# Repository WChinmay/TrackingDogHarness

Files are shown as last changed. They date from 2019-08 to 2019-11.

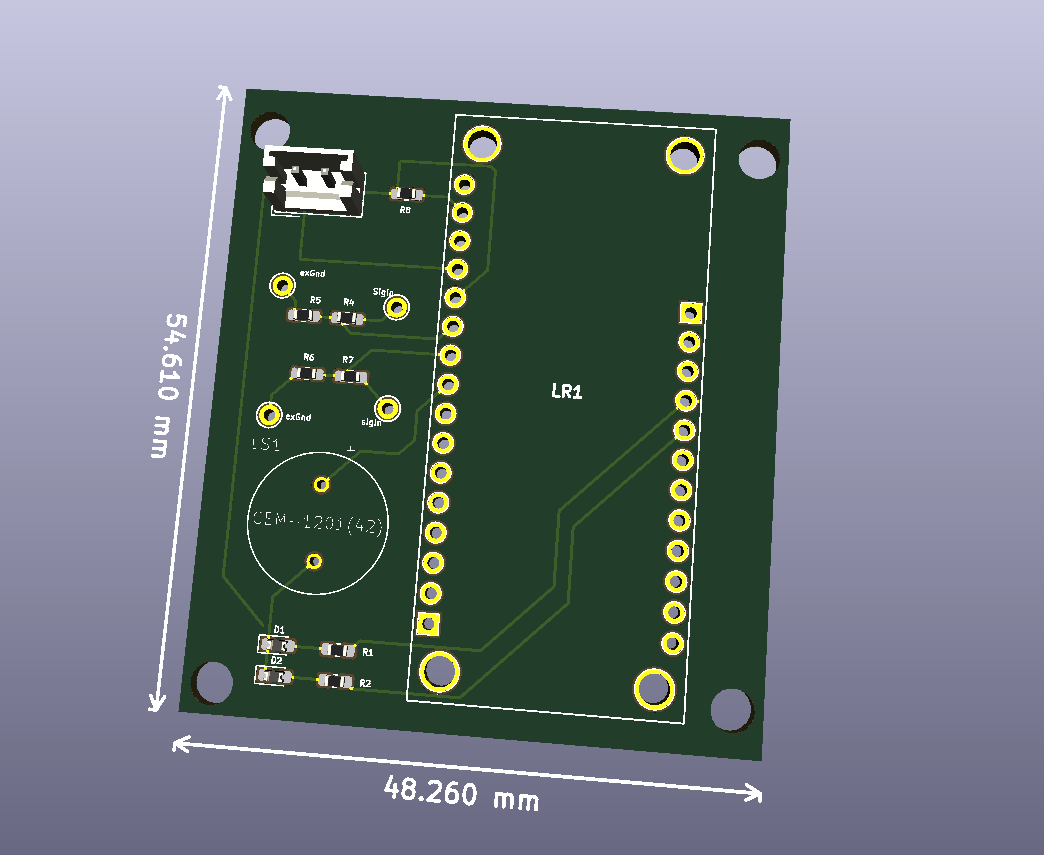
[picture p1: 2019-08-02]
PCBFiles/Block 2 Check off/3dmodel pcb.PNG

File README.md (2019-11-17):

# A Tracking Two-Way Communication Dog Harness that uses LoRa

## Description
This group project was developed for ECE 342 - Junior Design, a class at Oregon State University.

The harness can be used to reliably track your dog up to 0.7 miles (as of this version). It also provides temperature and battery voltage readings. Two other analog sensors can be incorporated into the harness. The battery life has been tested to be more than 12 hours and can probably last more than 48 hours on a single charge.

## Unique Feature
You can use the switch on the Alpha Transceiver to trigger a buzzer on the Beta Transceiver. Hence, your dog will be able to hear the buzzer. You can train your dog to "return" when it hears the buzzer. The buzzer can also be modified to ring at a frequency that only dogs and not humans can hear.

## Project Video
[Here](https://www.youtube.com/watch?v=w3UX0Dp_v24) is a link to the project video.

For more information, please contact:
wchinmay@gmail.com

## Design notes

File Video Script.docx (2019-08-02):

Video Script: 8-11 minutes

1. Introduction (~1 minute) - In this section of the video Chinmay Wadgaonkar, Noah Hoffman, and WeiHao Kuang will introduce themselves in that order. Along with the introduction we will also each state which blocks of the system that we are responsible for. Thus making a nice transition to the contributions part of the video.

Hey! We are team Tele(8) My name is Chinmay Wadgaonkar.

My name is Noah Hoffman.

My name is WeiHao Kuang, Our project is a telemetry device that will be mounted on a doggy harness. The system consists of a ruggedly enclosed transceiver on the harness we call the “Beta transceiver”. This can send GPS, temperature, and battery information to an “Alpha transceiver” that is connected to a MatLab map display at least 0.5 miles away. Also, on the Alpha side, the user can trigger a buzzer on the harness to signal the dog to return.

The 6 blocks that comprise this project are a MATLAB display and Alpha transceiver done by Chinmay, the Beta transceiver and sensing block by Noah, and the enclosure and buzzer sections by WeiHao.

2. Contributions
  a. Individual team members will talk about the parts that they were responsible for along with any specific design choices that they made and the materials they used to make their part. For this part the team members block overviews will be ordered by their first name.
    i. Chinmay Wadgaonkar (~1-2 minutes) - Chinmay will talk about the blocks that he was responsible for: the Alpha Transceiver and the MATLAB GUI display.

I was in charge of the Matlab display and the Alpha transceiver. The Alpha transceiver is the part of the system that receives temperature, battery voltage and temperature data from the beta and then passes it on to the the Matlab script through serial communication. The Alpha transceiver is also the part of the system which lets the user trigger a “buzzer” on the beta side by flipping a switch. I was also responsible for the two way communication incorporated in our system as one of our engineering requirements. I wrote the software which would help the alpha side detect if the switch is flipped and then would generate a “tone” of 4699 Hz. This can be modified to

    ii. Noah Hoffman(~1-2 minutes) - Noah will elaborate on the parts that he was responsible for: the Beta Transceiver and the Sensor Block.

With the Beta transceiver and the sensor block located on the harness, my job was a mix of hardware and software. The brains of our system are two Adafruit 32u4 LoRa feathers on either end communicating wirelessly. I wrote the software to reliably interpret and send battery, temperature, and and GPS data from the Beta feather to the Alpha feather. For the temperature we used a 10k Ohm Thermistor and our GPS was an add-on board built specifically for the feather microcontroller we were using.

    iii. WeiHao Kuang(~1-2 minutes) - WeiHao will explain his blocks which were the system enclosure and the system PCB.

I was in charge of the buzzer block and the system enclosure. The buzzer is integrated on the system PCB, which was designed using KiCad. Essentially the buzzer is used to call for the dog to come back to the owner when it is activated. To activate it we can simply flip a switch on the beta transceiver and through two ways serial communication was can create an audible beep to get the dog to return. The system enclosure designed with ruggedness in mind so that the system can endure various tests that are designed to test its limits, such as the drop system drop test and temperature extreme test.

  b. Evidence of collaboration (~1-2 minutes) - For this section of the video we will talk about the approach the team had for the finishing the project. Noah and Chinmay will talk about communicating over LoRa, and Weihao will talk about how the PCB and enclosure interact with the rest of the blocks. Also in this section of the video each member will talk about a challenge that they came across during the project and they will explain how they went about solving these with the help of other team members. (Collaboration video may be included).
3. Demo (> 2 minutes) - For the demo section of the video we will show a video including all the components of our whole system. We will elaborate in-depth about the functions of our blocks and Chinmay will introduce the entire system. Noah will talk about the intended application of the system. After that, Weihao will narrate as the other members show the system functioning.
4. Take-away Message/Improvement (~1 minute) - In this section of the video, Chinmay will talk about any future improvements that we can make to the system. Also, time willing, we may add possible applications of the system, Noah talking about including multiple beta receivers, and Weihao talking about path tracking and learning. In this section we will also each reflect on the project and what we took away from working on the project as a team.

Chinmay Wadgaonkar Noah Hoffman WeiHao Kuang

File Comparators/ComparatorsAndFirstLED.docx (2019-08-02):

Comparator.raw 5.OV

V(signal)

Vin006)

4.5V

4.0V

3.5V

3.ovh

2.5V

2.0v

1.5V

1.0v

0.5V

0.00+

Oms

2ms

4ms

6ms

8ms

10ms

12ms

14ms

16ms

18ms

Comparator.asc

-Vec

R1

R3

R4

R9

1000

1000

1000

1000

1000

Signal

R5

+

LT1017

2.2k

R6

+4211017

2.95

R7

1111017

2.2k

__ENU

411017

2.2k

v2 vi ŞINE(2.5 2.5 1k)

tran

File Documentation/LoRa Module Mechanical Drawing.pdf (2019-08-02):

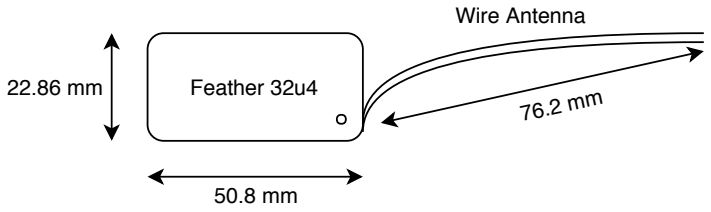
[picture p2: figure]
Feather 32u4; Wire Antenna

## Side View

## Top View

## Feather Module Mechanical Drawings

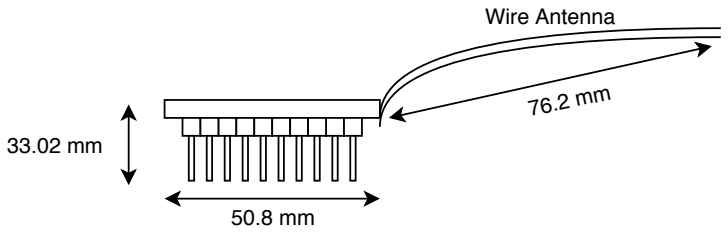
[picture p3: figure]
Wire Antenna

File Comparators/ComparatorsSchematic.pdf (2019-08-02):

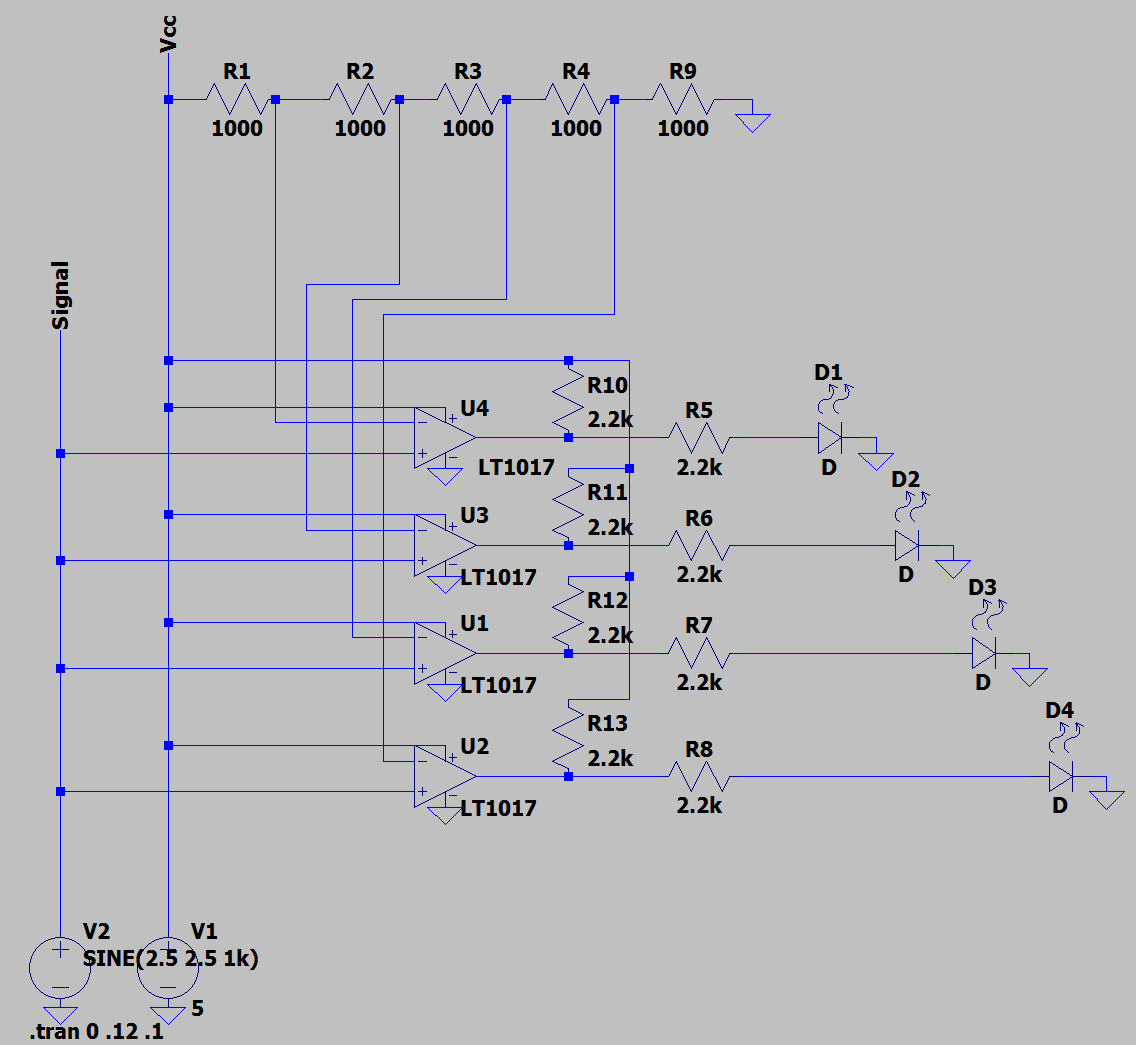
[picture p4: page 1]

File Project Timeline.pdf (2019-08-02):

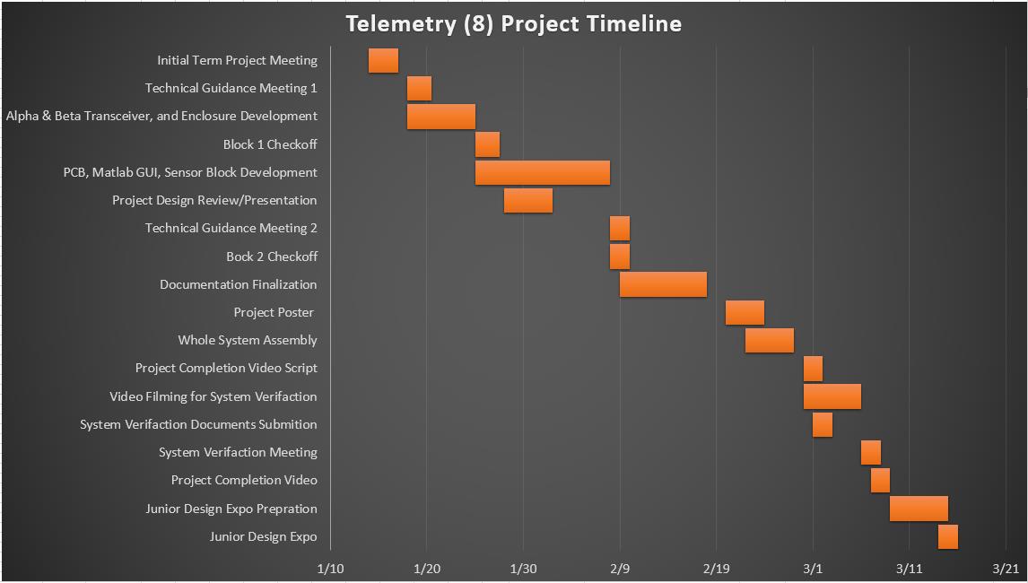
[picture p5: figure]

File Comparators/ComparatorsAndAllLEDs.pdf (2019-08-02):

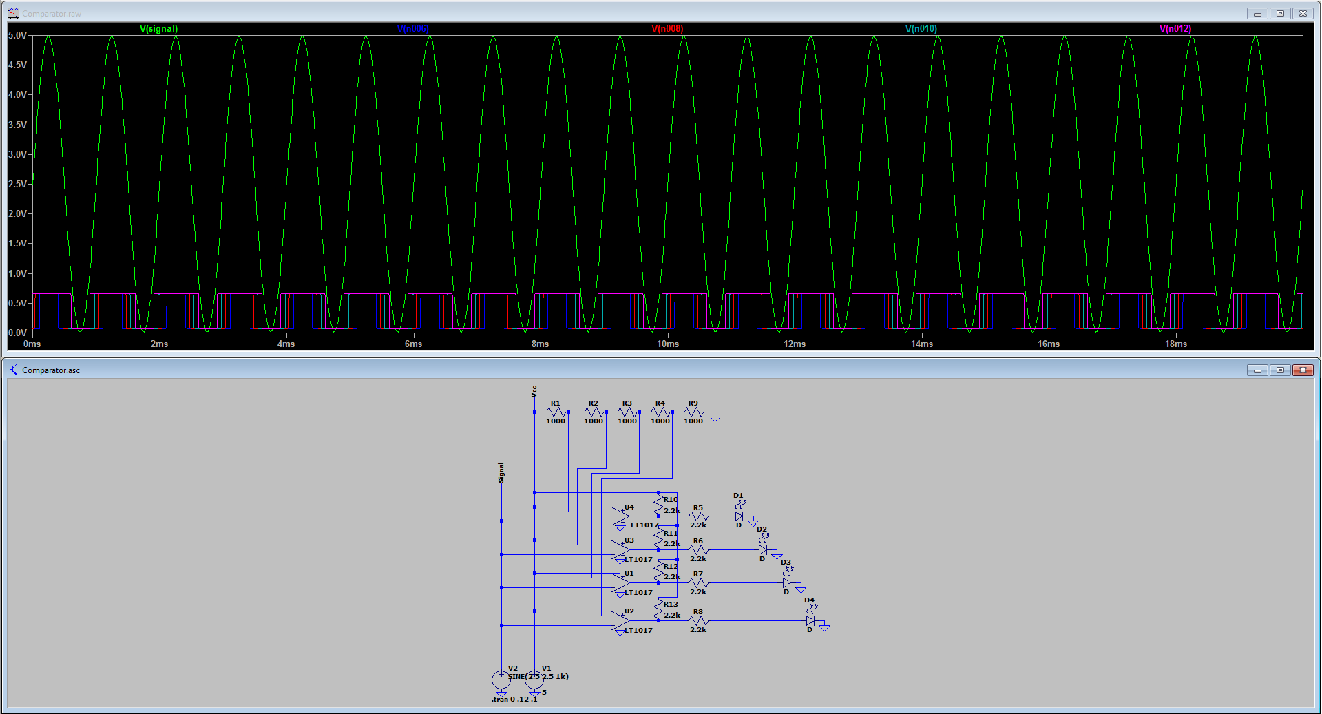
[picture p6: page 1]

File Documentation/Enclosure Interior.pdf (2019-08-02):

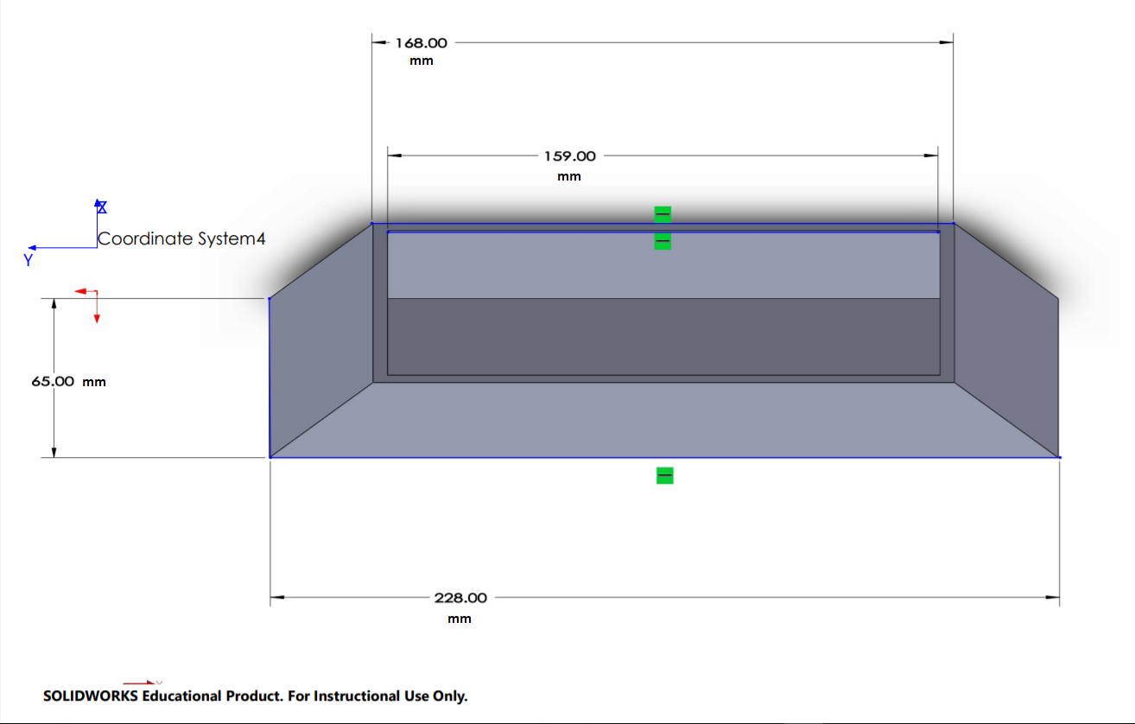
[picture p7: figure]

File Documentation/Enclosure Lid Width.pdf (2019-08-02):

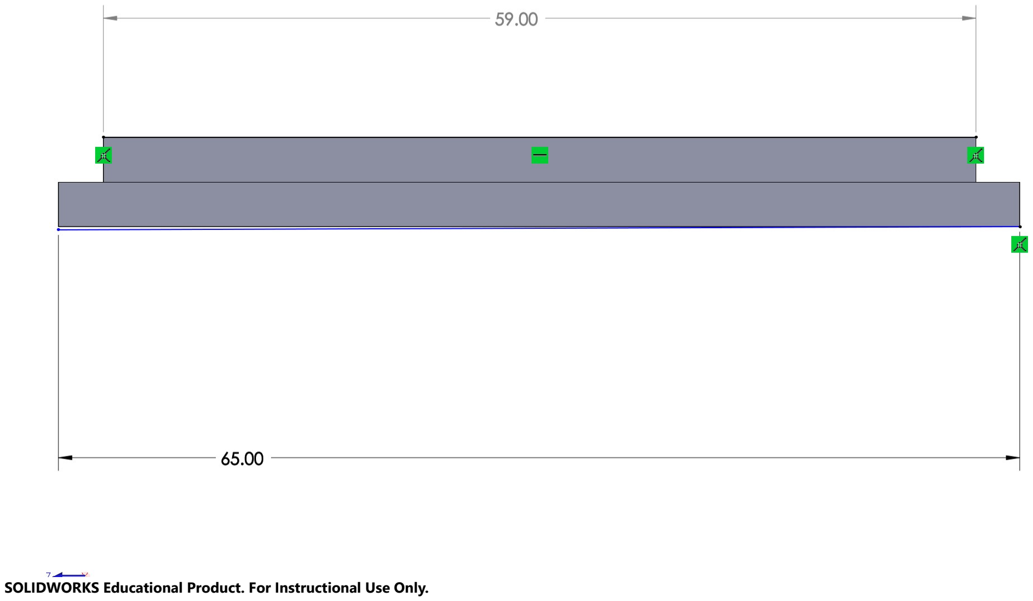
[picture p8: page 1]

SOLIDWORKS Educational Product. For Instructional Use Only.

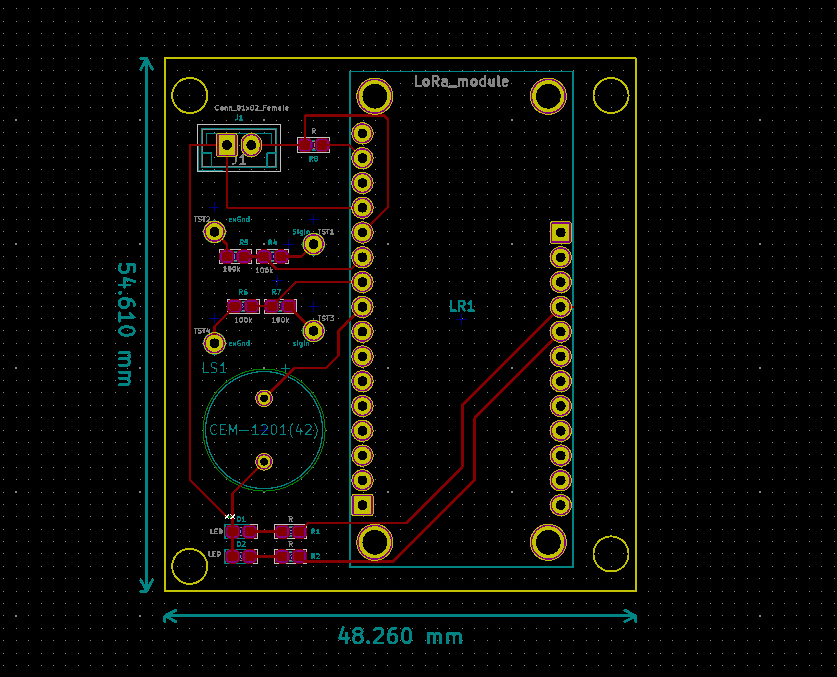
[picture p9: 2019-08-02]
PCBFiles/Block 2 Check off/pcbMain.PNG

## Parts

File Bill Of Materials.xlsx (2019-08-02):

Brand | Model/ Value/Type | Description | Foot Print | Reference | Qty | Cost | Link | DigiKey
Adafruit | Feather 32u4 RFM95 LoRa Radio | Microcontroller and Radio |  | LR1 (Alpha) | 2 | $69.90 | https://www.adafruit.com/product/3078 | ----
Adafruit | Stacking Headers | Header Pins | --- | ---- | 2 | $2.50 | https://www.adafruit.com/product/2830 | ----
Adafruit | FeatherWing | GPS Sensor | --- | ---- | 1 | $39.95 | https://www.adafruit.com/product/3133 | ----
 |  |  |  |  |  |  |  | ----
WlshiOT | B07LCKNN4H | U.FL IPEX to SMA Connector Antenna | --- | ---- | 1 | $11.89 | https://www.amazon.com/gp/product/B07LCKNN4H/ref=ppx_od_dt_b_asin_title_o00_s00?ie=UTF8&psc=1 | ----
Good2Go | Good2Go Pack Leader Green | Dog Harness | --- | ---- | 1 | $14.99 | https://www.petco.com/shop/en/petcostore/product/good2go-pink-dog-backpack | ----
ArtMinds | 16oz. Semi-Gloss DIY Outdoor Paint | Paint | ---- | ---- | 1 | $16.00 | https://www.michaels.com/16oz-semigloss-diy-outdoor-paint-by-artminds/M10515505.html | ----
Adafruit | ICR18650 Lithium Ion Battery 3.7 V 4400 mAh | Lithium Ion Batteries | ---- | ---- | 2 | $49.90 | https://www.adafruit.com/product/354 | ----
OSH Park | Custom Design | PCB | --- | ---- | 3 | $20.55 | https://oshpark.com/ | ----
Syncwire | Super-Durable Nylon Braided Fast Sync&Charging Cord | Mircro Usb Cable | --- | ---- | 2 | $7.99 | https://www.amazon.com/Micro-Cable-Android-Charger-Super-Durable/dp/B01GFB1SLC | ----
DigiKey | 1.37K Ohm (ERJ-3EKF1371V) | Resistor | R_0603_HandSoldering | R1, R2 | 2 | $0.20 | https://www.digikey.com/product-detail/en/panasonic-electronic-components/ERJ-3EKF1371V/P1.37KHCT-ND/198084 | P1.37KHCT-ND
DigiKey | 150K Ohm (ERJ-3GEYJ154V) | Resistor | R_0603_HandSoldering | R4, R5, R5, R7, R8 | 5 | $0.50 | https://www.digikey.com/product-detail/en/panasonic-electronic-components/ERJ-3GEYJ154V/P150KGCT-ND/134977 | P150KGCT-ND
DigiKey | CEM-1201 (42) | Buzzer | CEM-1201_42 | CEM-1201(42) | 1 | $0.74 | https://www.digikey.com/product-detail/en/cui-inc/CEM-1201-42/102-1151-ND/412410 | 102-1151-ND
DigiKey | LED (ERJ-3GEYJ154V) | LED | LED_0603_HandSoldering | D1, D2 | 2 | $0.44 | https://www.digikey.com/product-detail/en/rohm-semiconductor/SML-D12V1WT86/SML-D12V1WT86CT-ND/5843857 | SML-D12V1WT86CT-ND
DigiKey | Female JST connector (ERJ-3GEYJ154V) | JST connector | Pin_Header_Straight_1x02_Pitch2.54mm | J1 | 1 | $0.11 | https://www.digikey.com/product-detail/en/harwin-inc/M20-9990246/952-2262-ND/3728226 | 952-2262-ND
OCR | 10K Ohm Thermal Sensor (5pc) | Thermistor | ---- | ---- | 1 | $9.99 | https://www.amazon.com/OCR-Waterproof-Digital-Thermal-Temperature/dp/B0185P4MVO?s=gateway | ----
Permatex | Permatex® Clear RTV Silicone Adhesive Sealant | Sealant | ---- | ---- | 1 | $5.49 | https://www.permatex.com/products/adhesives-sealants/sealants/permatex-clear-rtv-silicone-adhesive-sealant/ | ----
RadioShack | Project Enclosure (4x2x1-Inch) | Small enclosure | ---- | ---- | 1 | $6.00 | https://www.radioshack.com/products/radioshack-project-enclosure-4x2x1 | ----
XSories | Bendy Flexible Camera Tripod For GoPro, Digital, And Action Sports Cameras | Tripod Mount | ---- | ---- | 1 | $30.99 | https://www.amazon.com/dp/B00OKYYVDO/ref=twister_B00W52UZJC?_encoding=UTF8&psc=1 | ----
TekBots | Custom Design | Body of 3D printed enclosure | ---- | ---- | 1 | $38 | http://eecs.oregonstate.edu/education/3dprinter/ | ----
TekBots | Custom Design | Lid of 3D printed enclosure | ---- | ---- | 1 | $15 | http://eecs.oregonstate.edu/education/3dprinter/ | ----
ThingM | USB Extension cable, 5ft | USB extension cable | ---- | ---- | 1 | $3.00 | http://buy.thingm.com/USB-Extension-cable-5-ft_p_37.html | ----
Uxcell | Uxcell a12081700ux0133 Toggle Switch | Switch | Pin_Header_Straight_1x02_Pitch2.54mm | SW1 | 1 | $4.24 | https://www.amazon.com/Uxcell-a12081700ux0133-Toggle-Terminal-Latching/dp/B00RV9ULFM?s=industrial | ----

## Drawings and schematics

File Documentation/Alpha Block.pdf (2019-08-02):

# Drawing 22.86mm

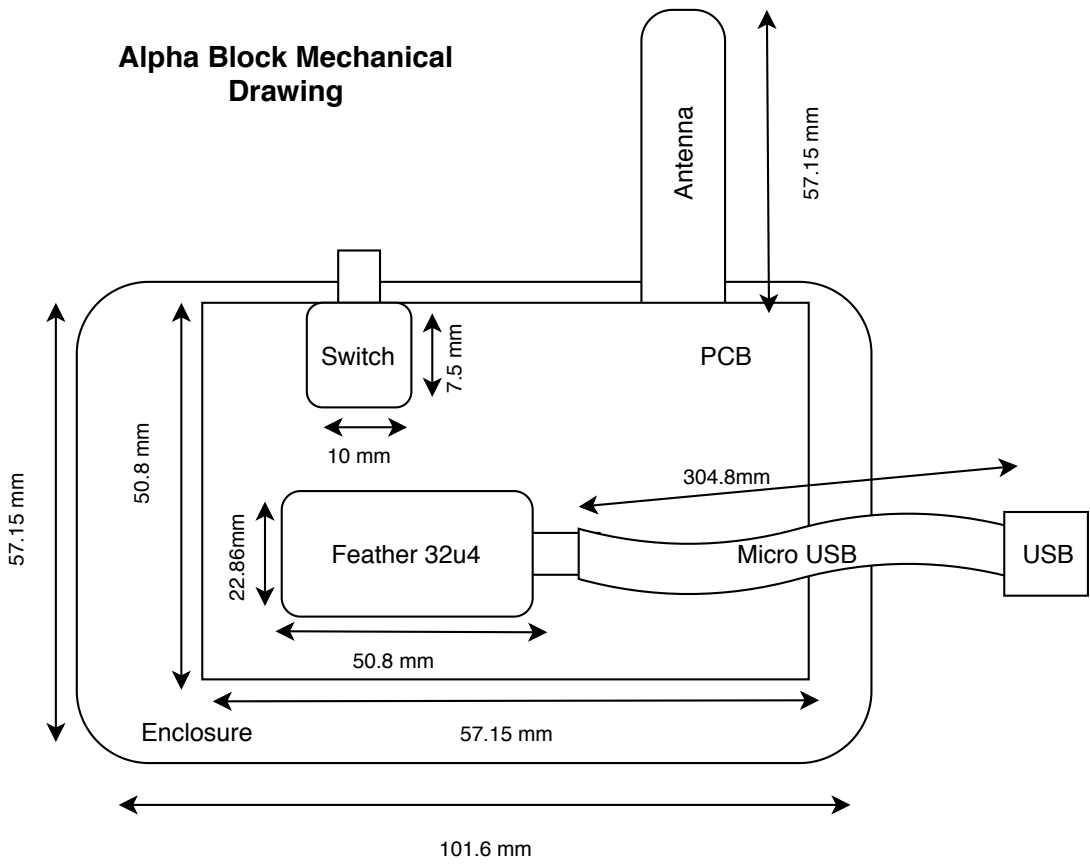
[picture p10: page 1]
Feather 32u4; Micro USB; Switch; USB; PCB; Antenna; Enclosure

Alpha Block Mechanical

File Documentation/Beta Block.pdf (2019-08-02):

# PCBAntenna

# Drawing 22.86mm

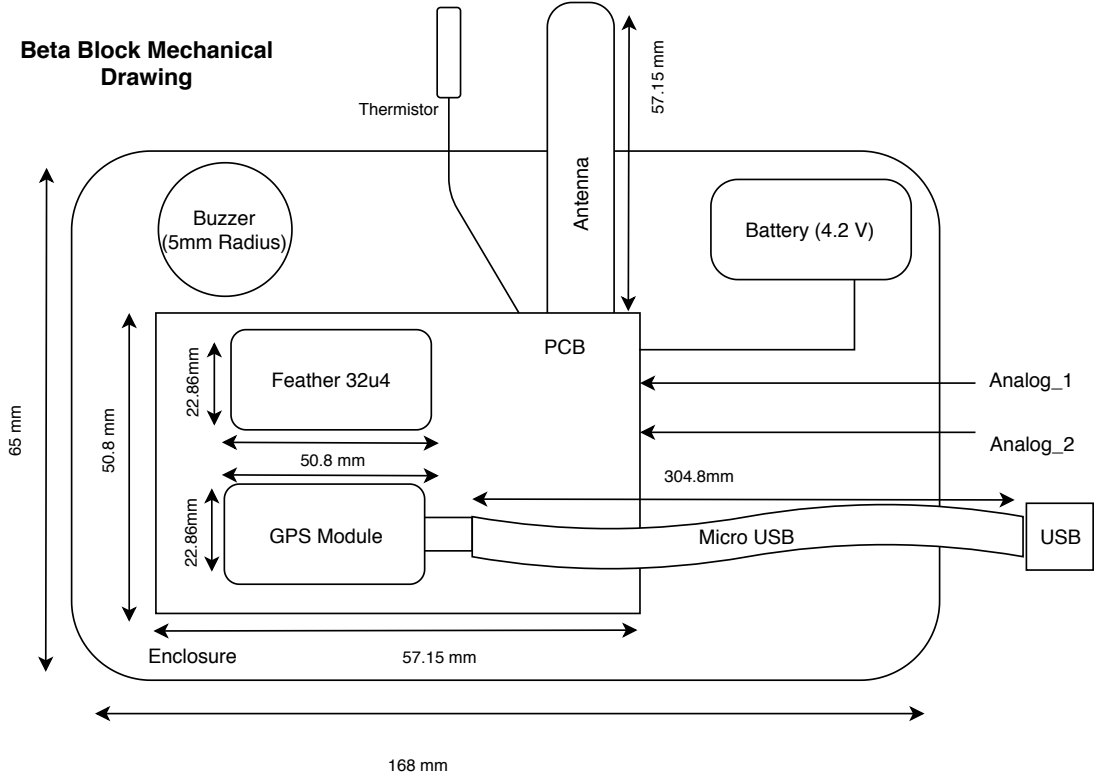
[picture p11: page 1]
Feather 32u4; Micro USB; USB; Enclosure; GPS Module; Buzzer (5mm Radius); Thermistor; Analog_1; Analog_2; Battery (4.2 V)

Beta Block Mechanical

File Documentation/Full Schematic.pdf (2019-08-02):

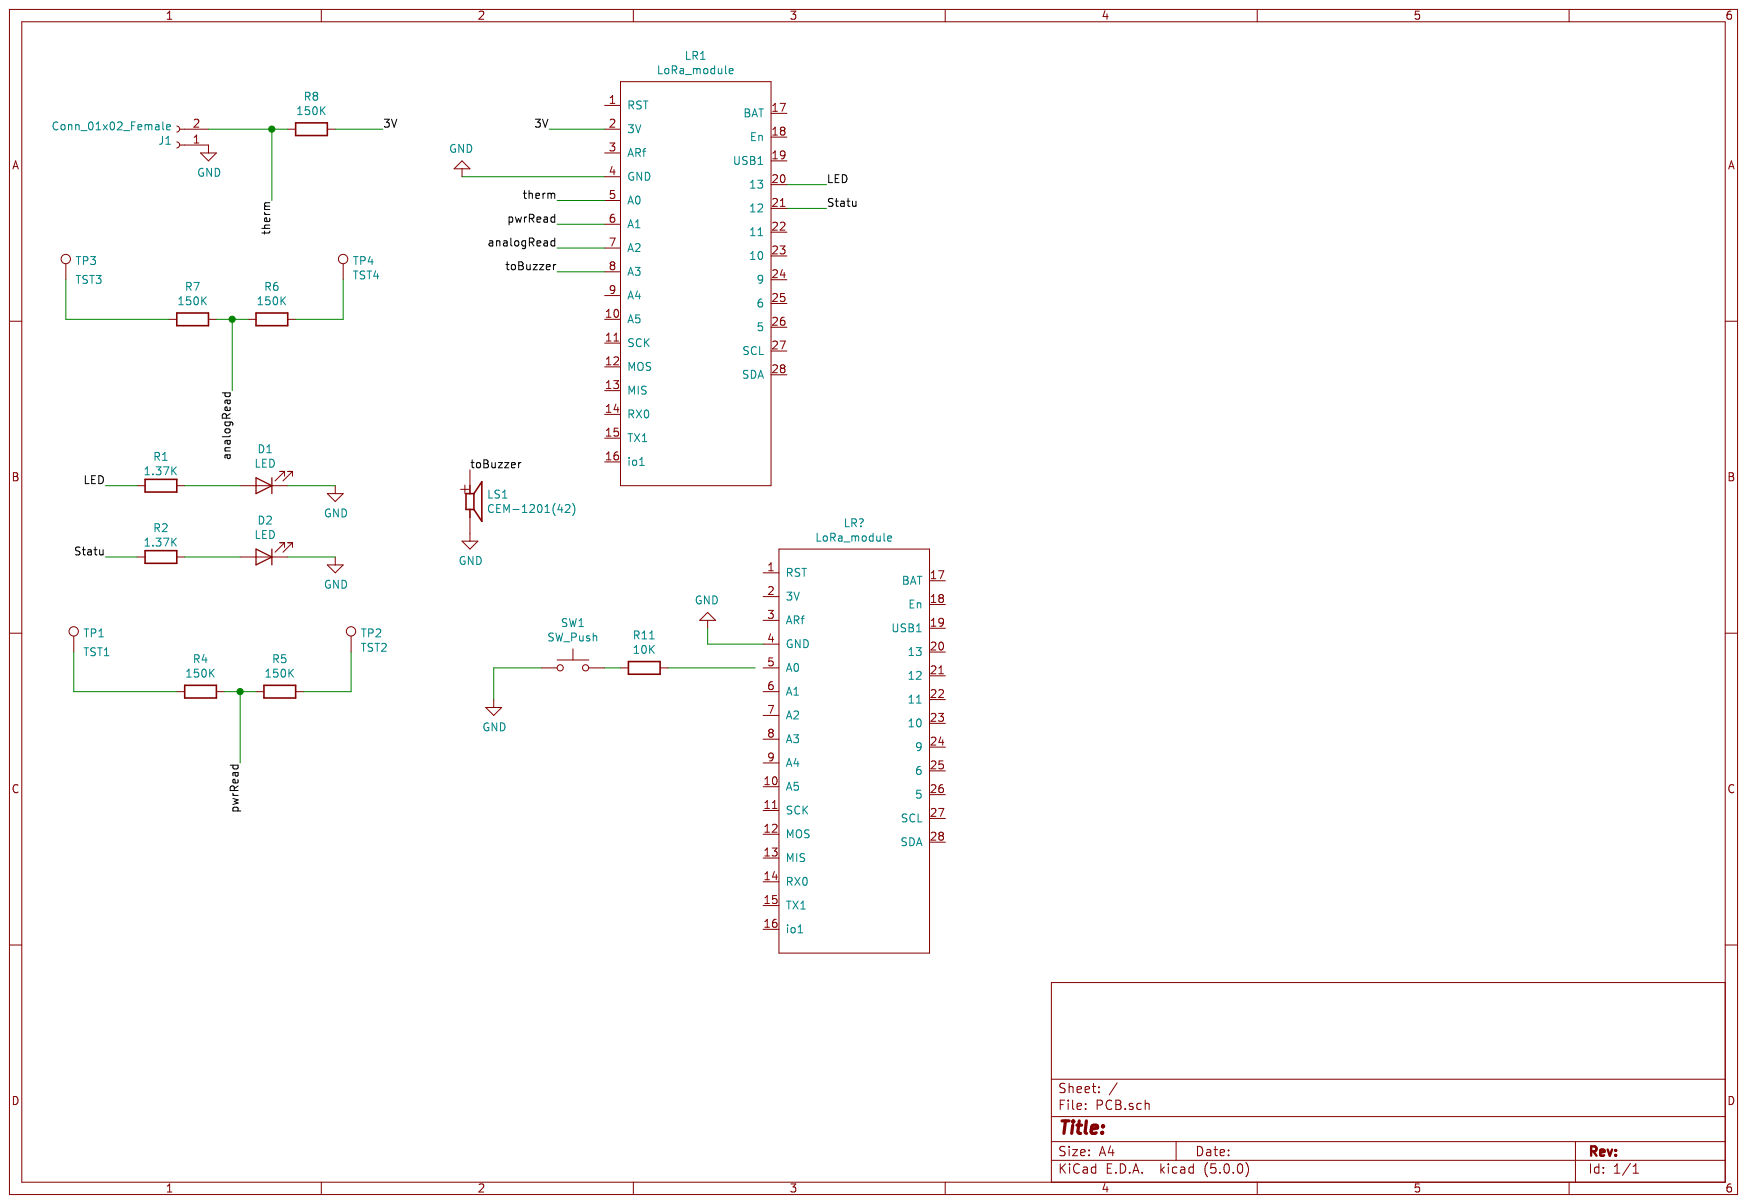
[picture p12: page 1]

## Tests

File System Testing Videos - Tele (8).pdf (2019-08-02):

| Customer Requirement | Engineering Requirement | Video Link
1 | The system must operate a long time. | The system must log and transmit data for at least 12 hours on a single charge. | https://www.youtube.com/watch?v=tkDF9gEU2gM (https://www.youtube.com/watch?v=tkDF9gEU2gM)
2 | The system must be accurate. | The system must log GPS data with at least a 10 meter accuracy and 2 analog voltages from 0.2 -4.5V within 5% or 0.1V of real values, whichever is larger. | https://youtu.be/nMwKtgHTGS 0 (https://youtu.be/nMwKtgHTGS0)
3 | The system needs to be robust. | The system will function to all other requirements while: Being submerged to 1 cm of depth for one second, operating at -10°C, operating above 85°C, and after being dropped on concrete from 3 feet at least 5 times. | https://www.youtube.com/watch?v=rk-2Pc-Hki8&t=4s (https://www.youtube.com/watch?v=rk-2Pc-Hki8&t=4s)
4 | The system must transmit data. | The system must transmit its measurements at least 0.5 miles with at least 95% of the packets being received by the the alpha system over an hour. | https://www.youtube.com/watch?v=7LX2uhGYKJg (https://www.youtube.com/watch?v=7LX2uhGYKJg)
5 | The system must present data. | The system must display data in Matlab, with a professional looking overlay of a satellite map image. | https://www.youtube.com/watch?v=-FKc55mf-XE&t=7s (https://www.youtube.com/watch?v=-FKc55mf-XE&t=7s)
6 | The system must be lightweight. | The beta side of the system must be light enough to be wearable by a dog. Hence, the beta system can weigh up to 7 pounds or 12% of the dog’s body weight, whichever is less. | https://www.youtube.com/watch?v=5BAzrrR3Tn0 (https://www.youtube.com/watch?v=5BAzrrR3Tn0)
7 | The user can remotely trigger a bell sound on the beta-transceiver. | The system has two way communication. A button press by the user on the alpha side must trigger a buzzer on the beta side of the system. | https://www.youtube.com/watch?v=OC4kbGjPUW8 (https://www.youtube.com/watch?v=OC4kbGjPUW8)

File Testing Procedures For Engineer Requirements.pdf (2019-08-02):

1) Customer Requirement: System must operate a long time.
Engineering Requirement: The system must log and transmit data for at least 12 hours on a single charge.
a) To test this requirement for our system we will keep both the alpha and beta transceivers on for 12 hours. The alpha transceiver will keep a log file that will check whether the beta transceiver is still running. If the log file consists of data that is consistent and the data entries correspond to 12 hours of operations, the test will be completed and passed.
2) Customer Requirement: The system must be accurate.
Engineering Requirement: The system must log GPS data with at least a 10 meter accuracy and 2 analog voltages from 0.2 - 4.5V within 5% or 0.1V of real values, whichever is larger.
a) For testing the GPS accuracy we will use 3 known locations and their GPS coordinates. The system will gather gps data at the known location for 5 minutes. If the average of all the GPS data is within 10 metres of the known GPS coordinates, the test passes.
b) For the 2 analog voltage test the system will read in a voltage from 0.2V to 4.5 V by placing an input voltage to the onboard voltage dividers which will be sent to the alpha transceiver and stored onto a log file using MATLAB. If the values that are stored onto MATLAB are within 5% or 0.1V of the real value (whichever is larger), then the test passes.
3) Customer Requirement: The system needs to be robust:
Engineering Requirement:The system will function to all other requirements while: Being submerged to 1 cm of depth for one second, operating at -10°C, operating above 85°C, and after being dropped on concrete from 3 feet at least 5 times
a) Testing the Water Blocking Ability of the Enclosure
i) For this test we would need to fill a sink of water, then line the enclosure with paper towels so that it will be visible if water leaks into the enclosure.
ii) | Next we will fully submerged (1 cm depth) into water for one second then
| take it out. If the paper towels inside are not stained from submerging the
| enclosure in the water then this part of the test is passed.
b) Temperature Operation Range of the Enclosure: Checking if the enclosure can operate in -10℃ or Lower temperature (Cold Extreme).
i) First place the system into a freezer that is -10 degrees. Next, start a
| timer for 5 minutes and check back on the system enclosure when the
| time is up. If the system is still operational and data is being sent to the
| alpha-transceiver for the duration of the five minutes then this test passes.

c) Checking if the enclosure can operate and 85℃ or Higher (Heat Extreme)
i) First preheat the oven to 87 degrees celsius, and place the system in it, Set a timer for 10 minutes and check the enclosure when the time is up. Immediately check for structural weaknesses, if there are not any then the enclosure passed the heat extreme verification test.
d) Drop Shock Robustness
i) For this test we need to drop that enclosure which will be in the dog harness 5 times from a height of 3 feet on concrete.This test will be conducted when the when both beta and the alpha transceivers are running to show that the system will survive and continue to operate. If the system is still transmitting data after the series of 5 drops then this test is passed.
4) Customer Requirement: The system must transmit data.
Engineering Requirements: The system must transmit its measurements at least 0.5 miles with at least 95% of the packets being received by the the alpha-transceiver over an hour.
a) For this test we will be be sending the packet numbers from the beta to alpha transceiver. On both transceivers we will be keeping running totals of the amount of packets during operation which will be over the hour for this test. Once the hour has passed, we will take that ratio of the packets received by the alpha transceiver over the packets sent by that beta transceiver; it that ratio if at least 95 percent that this part of the test is passed.
5) Customer Requirement: The system must present data.
Engineering Requirement: The system must display data in Matlab, with a professional looking overlay of a satellite map image.
a) To test this engineering requirement, we will show that the data retrieved from the beta transceiver can be displayed on the MATLAB GUI with the temperature, battery voltage, the two analog voltage readings, and the GPS data.
`
6) Customer Requirement: The system must be lightweight.
Engineering Requirement: The beta side of the system must be light enough to be wearable by a dog. Hence, the beta system can weigh up to 7 pounds or 12% of the dog’s body weight, whichever is less.
a) To test this requirement we will just weigh the system on a balanced and accurate scale and if the system is less than 7 pounds this test is passed.

7) Customer Requirement: The user can remotely trigger a bell sound on the beta-transceiver.
Engineering Requirement: The system has two way communication. A button press by the user on the alpha side must trigger a buzzer on the beta side of the system.
a) For this test, to show that the system has two way communication, the alpha-transceiver will trigger a response on the beta-transceiver side of the system. A mechanical switch will trigger the beta-side buzzer running at 4699 Hz. If a buzzer sound is triggered when the mechanical switch on the alpha side is pressed then this test passes.

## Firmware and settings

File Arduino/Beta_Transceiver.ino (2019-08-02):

/* Include header files */
#include <Adafruit_GPS.h>
#include <SoftwareSerial.h>
#include <SPI.h>
#include <RH_RF95.h>
#include <stdlib.h>
#include <string.h>

/* RFM95 definitions */
#define RFM95_CS 8
#define RFM95_RST 4
#define RFM95_INT 7

/* Thermistor constants */
#define THERMISTORNOMINAL 10000
#define SERIESRESISTOR 150000   // Change this to the value of the series resistor if the resistor on the current PCB is changed

int16_t packetnum = 0;    // 16 bit integer to hold packets
char latBuffer[10];       // To hold latitude from GPS
char longBuffer[10];      // To hold longitude from GPS
String temp;              // To hold temperature from thermistor

/* Default constants for dummy data */
float Vbatt = 3.20;
float temperature = 70.42;

/* Pin declarations */
#define VBATPIN A9    // Pin for battery voltage
#define TEMPPIN A0    // Pin for temperature
#define PWMPIN  A3    // Pin for pulse width modulation
#define ANALOG1 A1    // Pin for analog reading 1
#define ANALOG2 A2    // Pin for analog reading 2

// Change to 434.0 or other frequency, must match RX's freq!
#define RF95_FREQ 915.0

// Singleton instance of the radio driver
RH_RF95 rf95(RFM95_CS, RFM95_INT);

// The name of the hardware serial port
#define GPSSerial Serial1

// Connect to the GPS on the hardware port
Adafruit_GPS GPS(&GPSSerial);
     
// Set GPSECHO to 'false' to turn off echoing the GPS data to the Serial console
// Set to 'true' if you want to debug and listen to the raw GPS sentences
#define GPSECHO false

/* Start millisecond timer for GPS */
uint32_t timer = millis();


void setup()
{
  //while (!Serial);  // uncomment to have the sketch wait until Serial is ready
  pinMode(RFM95_RST, OUTPUT);   // Set initila pin mode
  digitalWrite(RFM95_RST, HIGH);    // Set initial pin mode
  // connect at 115200 so we can read the GPS fast enough and echo without dropping chars
  // also spit it out
  Serial.begin(115200);   // Start serial at 115200 baud
  // Serial.println("Adafruit GPS library basic test!");
     
  // 9600 NMEA is the default baud rate for Adafruit MTK GPS's- some use 4800
  GPS.begin(9600);
  GPS.sendCommand(PMTK_SET_NMEA_OUTPUT_RMCGGA);
  // Set the update rate
  GPS.sendCommand(PMTK_SET_NMEA_UPDATE_1HZ); // 1 Hz update rate
     
  // Request updates on antenna status, comment out to keep quiet
  GPS.sendCommand(PGCMD_ANTENNA);
  delay(100);
  /* LoRa starts */
  digitalWrite(RFM95_RST, LOW);
  delay(10);
  digitalWrite(RFM95_RST, HIGH);    // Checking LEDs
  delay(10);
  /* Check if LoRa radio works */
  while (!rf95.init()) {
    Serial.println("LoRa radio init failed");
    while (1);
  }
  /* Otherwise, radio has initialized */
  Serial.println("LoRa radio init OK!");

  // Defaults after init are 434.0MHz, modulation GFSK_Rb250Fd250, +13dbM
  if (!rf95.setFrequency(RF95_FREQ)) {
    Serial.println("setFrequency failed");
    while (1);
  }

  /* Use this to set our own frequency */
  Serial.print("Set Freq to: "); Serial.println(RF95_FREQ);
  
  /* The default transmitter power is 13dBm, using PA_BOOST.
     If you are using RFM95/96/97/98 modules which uses the PA_BOOST transmitter pin, then 
     you can set transmitter powers from 5 to 23 dBm */
  rf95.setTxPower(23, false);
  delay(1000);
  /* END OF LORA */
  
  // Ask for firmware version
  GPSSerial.println(PMTK_Q_RELEASE);
}

void loop() // run over and over again
{
  // read data from the GPS in the 'main loop'
  char c = GPS.read();
  if (GPSECHO)
    if (c) Serial.print(c);
    // if a sentence is received, we can check the checksum, parse it...
  
  if (GPS.newNMEAreceived()) 
  {
    // a tricky thing here is if we print the NMEA sentence, or data
    // we end up not listening and catching other sentences!
    // so be very wary if using OUTPUT_ALLDATA and trytng to print out data
    Serial.println(GPS.lastNMEA()); // this also sets the newNMEAreceived() flag to false
    if (!GPS.parse(GPS.lastNMEA())) // this also sets the newNMEAreceived() flag to false
      return; // we can fail to parse a sentence in which case we should just wait for another
  }
  // if millis() or timer wraps around, we'll just reset it
  if (timer > millis()) 
  {
    timer = millis();
  }
  // set up common variables and reading in values from analog pins
  float measuredvbat = analogRead(VBATPIN);
  float measuredtemp = analogRead(TEMPPIN);
  int16_t measureda1 = analogRead(ANALOG1);
  int16_t measureda2 = analogRead(ANALOG2);
  char radiopacket[75] = "                                                                          ";    // This is 75 spaces since it needs to hold something when initialized
  // approximately every 2 seconds or so, print out the current stats
  
  if (millis() - timer > 2000) 
  {
    timer = millis(); // reset the timer
    if (GPS.fix)  // If GPS has a fix
    {
      dtostrf(GPS.latitudeDegrees, 10, 5, latBuffer);   // Convert the values to strings to send them over LoRa
      temp += latBuffer;    // Add latitude to what is sent
      temp += ", ";   // Add delimiter
      
      dtostrf(GPS.longitudeDegrees, 10, 5, longBuffer);   // Convert the values to strings to send them over LoRa
      temp += longBuffer;   // Add longitude to what is sent
      temp += ", ";   // Add delimiter

      /* Calculate human sensible value from voltage raw data */
      measuredvbat *= 2;    
      measuredvbat *= 3.3;
      measuredvbat /= 1024;
      Vbatt = measuredvbat;
      temp += Vbatt;   // Add battery voltage to what is sent
      temp += ", ";    // Add delimiter

      /* Calculate human sensible value from thermistor raw data using the Steinhart equation*/
      measuredtemp = 1023/measuredtemp - 1;
      measuredtemp = SERIESRESISTOR / measuredtemp;
      float steinhart = measuredtemp / THERMISTORNOMINAL;
      steinhart = log(steinhart);
      steinhart /= 3950;                  // 3950 is the coeeficient of the thermistor
      steinhart += 1.0 / (25 + 273.15);   // 25 is the nominal temperature assumption
      steinhart = 1.0 / steinhart;
      steinhart -= 273.15;
      temperature =  steinhart;
      temp += temperature;  // Add temperature to what is sent
      temp += ", ";   // Add delimiter

      /* Calculate human sensible value from voltage reading 1 raw data */
      measureda1 *= 2;    
      measureda1 *= 3.3;
      measureda1 /= 1024;
      temp += measureda1;   // Add voltage reading 1 to what is sent
      temp += ", ";   // Add delimiter

      /* Calculate human sensible value from voltage reading 2 raw data */
      measureda2 *= 2;    
      measureda2 *= 3.3;
      measureda2 /= 1024;
      temp += measureda2;   // Add voltage reading 2 to what is sent
      temp += ", ";   // Add delimiter

      packetnum++;    // Increment packet count
      temp += packetnum;    // Add packet number to what is sent
      temp += ", ";   // Add delimiter
      
      delay(1000); // Wait 1 second between transmits, could also 'sleep' here!
      Serial.println("Transmitting..."); // Send a message to rf95_server

      /* Clear the whole readio packet using spaces */
      for (int i = 0; i < 74; i++)
      {
        radiopacket[i] = ' ';
      }

      /* Set temp into radio packet */
      for (int i = 0; i < temp.length(); i++)
      {
        radiopacket[i] = temp[i];
      }

      /* Debugging using serial monitor */
      Serial.print("Sending "); 
      Serial.println(radiopacket); 
      Serial.println(temp);

      /* Actually send the whole radio packet using LoRa */
      Serial.println("Sending...");
      delay(10);
      rf95.send((uint8_t *)radiopacket, 75);

      /* Wait till all the packets have been sent */
      Serial.println("Waiting for packet to complete..."); 
      delay(10);
      rf95.waitPacketSent();
      
      // Now wait for a reply
      uint8_t buf[RH_RF95_MAX_MESSAGE_LEN];
      uint8_t len = sizeof(buf);
      Serial.println("Waiting for reply...");
      if (rf95.waitAvailableTimeout(1000))
      {  
      /* Receive message using LoRa for buzzer */
      if (rf95.recv(buf, &len))
      {
        // Print received information to serial to help with debugging
        Serial.print("Got reply: ");
        Serial.println((char*)buf);
        Serial.print("RSSI: ");
        Serial.println(rf95.lastRssi(), DEC); 

        // Use received buf to determine whether to tone or not
        if(strcmp(buf, "1") == 0)   // This evaluate to true if the user wants the buzzer
        {
          tone(PWMPIN, 4699, 1000);   // We can set this frequency to be above a humans range of hearing 
                                      // but in the range of a dogs hearing. For testing purposes the frequency has been
                                      // set lower to 4699 Hz. It plays the tone for 1000 milliseconds 
        }
      }
      else
      {
        Serial.println("Receive failed");   // For debugging in serial
      }
    }
    else
    {
      Serial.println("No reply, is there a listener around?");    // If no receiving
    }
   }
 }
 temp = "";   // Reset temp to not have garbage in buffer
}

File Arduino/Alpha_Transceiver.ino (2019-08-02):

// Feather9x_RX
// -*- mode: C++ -*-


/* Include header files  */
#include <SPI.h>
#include <RH_RF95.h>

/* Define pin on the arduino that the switch is connected to */
#define SWITCHPIN  A0

/* for Feather32u4 RFM9x */
#define RFM95_CS 8
#define RFM95_RST 4
#define RFM95_INT 7

// Change to 434.0 or other frequency, must match RX's freq!
#define RF95_FREQ 915.0

// Singleton instance of the radio driver
RH_RF95 rf95(RFM95_CS, RFM95_INT);

// Blink this LED when alpha receives
#define LED 13

void setup()
{
  // Initialize pins
  pinMode(LED, OUTPUT);
  pinMode(RFM95_RST, OUTPUT);
  digitalWrite(RFM95_RST, HIGH);

  // Start serial
  Serial.begin(115200);

  // Delay for startup
  delay(100);

  // Manual Reset to Check
  digitalWrite(RFM95_RST, LOW);
  delay(10);
  digitalWrite(RFM95_RST, HIGH);
  delay(10);

  // Print error message if LoRa fails
  while (!rf95.init()) {
    //Serial.println("LoRa radio init failed");
    while (1);
  }
  // Otherwise print OK message
  //Serial.println("LoRa radio init OK!");

  // Defaults after init are 434.0MHz, modulation GFSK_Rb250Fd250, +13dbM
  if (!rf95.setFrequency(RF95_FREQ)) {
    //Serial.println("setFrequency failed");
    while (1);
  }
  // Use to manually set frequency while testing in serial monitor
  // Serial.print("Set Freq to: "); Serial.println(RF95_FREQ);

  // Defaults after init are 434.0MHz, 13dBm, Bw = 125 kHz, Cr = 4/5, Sf = 128chips/symbol, CRC on

  // The default transmitter power is 13dBm, using PA_BOOST.
  // If you are using RFM95/96/97/98 modules which uses the PA_BOOST transmitter pin, then
  // you can set transmitter powers from 5 to 23 dBm:
  rf95.setTxPower(23, false);   // Use to boost power
}

void loop()
{
  if (rf95.available())   // If radio is available
  {
    // Should be a message for us now
    uint8_t buf[RH_RF95_MAX_MESSAGE_LEN];
    uint8_t len = sizeof(buf);    // Setting buffer

    if (rf95.recv(buf, &len))   // Whatever is received will be in buf
    {
      digitalWrite(LED, HIGH);    // To indicate that somethign was received
      // Serial.print("Got: ");
      Serial.println((char*)buf);  // Send what was received to serial monitor for Arduino debugging
      /* Use to print signal strength to test how far we can take the beta transceiver */
      // Serial.print("RSSI: ");   
      // Serial.println(rf95.lastRssi(), DEC);

      // Send a reply
      if(digitalRead(SWITCHPIN) == HIGH)    // This means the user wants the beta transceiver to buzz
      {
        uint8_t data[] = "1";   // Send buzz
        rf95.send(data, sizeof(data));  // Send using LoRa radio
        rf95.waitPacketSent();    // Wait till all the packets are sent
        // Serial.println("Sent a reply");
        digitalWrite(LED, LOW);   // Physical indication of sent signal
      }
      else    // If the user doesn't want the beta transceiver to buzz
      {
        uint8_t data[] = "0";   // Send no buzz
        rf95.send(data, sizeof(data));  // Send using LoRa radio
        rf95.waitPacketSent();  // Wait till all the packets are sent
        // Serial.println("Sent a reply");
        digitalWrite(LED, LOW); // Physical indication of sent signal
      }
    }
    else
    {
      /* Check here to know if Receive is failing */
      // Serial.println("Receive failed");
    }
  }
}
